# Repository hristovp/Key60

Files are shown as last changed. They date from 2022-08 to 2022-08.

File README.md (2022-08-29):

I made a custom 60%(61 keys) keyboard with custom made PCB using (ATmega32u4) which is completely customizable.
I am adding evething needed for the project. It just take time to check if everythins works. :D

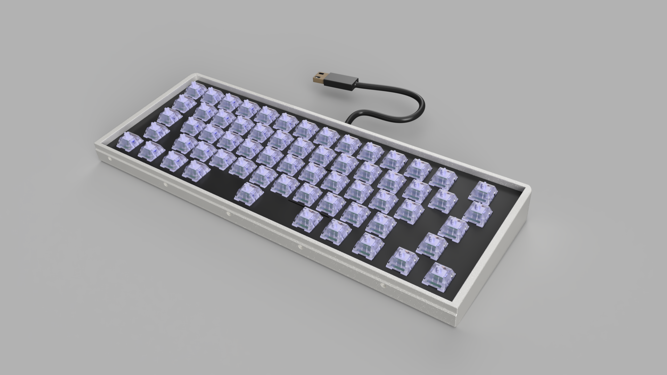
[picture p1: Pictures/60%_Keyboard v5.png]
<kbd></kbd> <kbd></kbd>
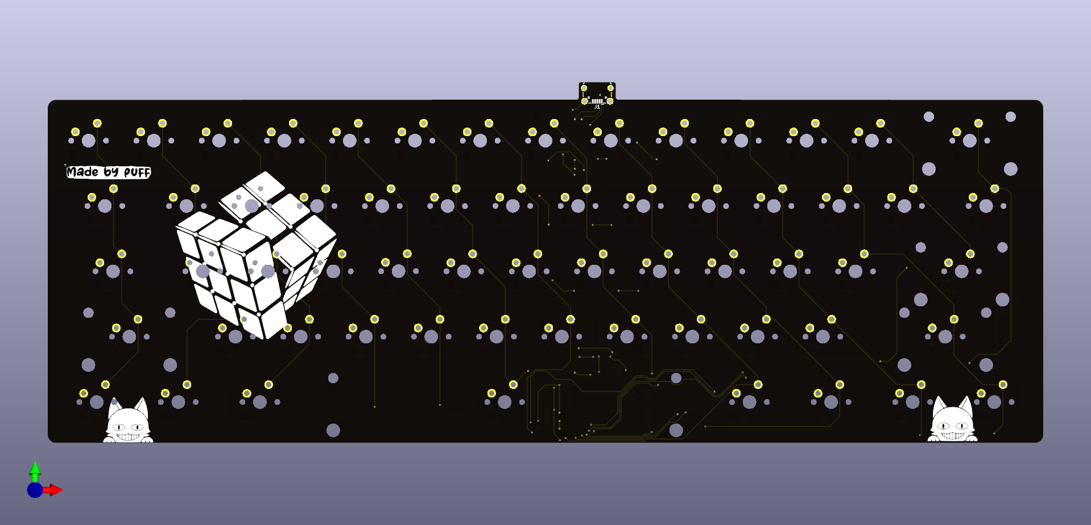
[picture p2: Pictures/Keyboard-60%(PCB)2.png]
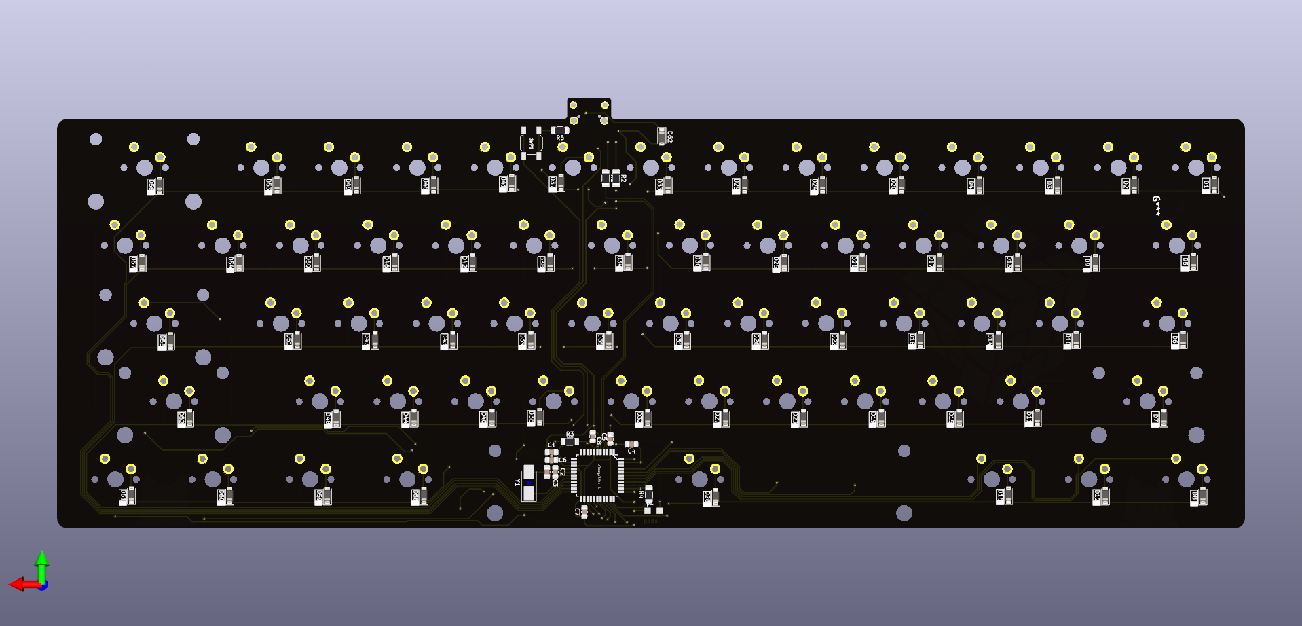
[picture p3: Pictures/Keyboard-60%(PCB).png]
<kbd></kbd> <kbd></kbd>

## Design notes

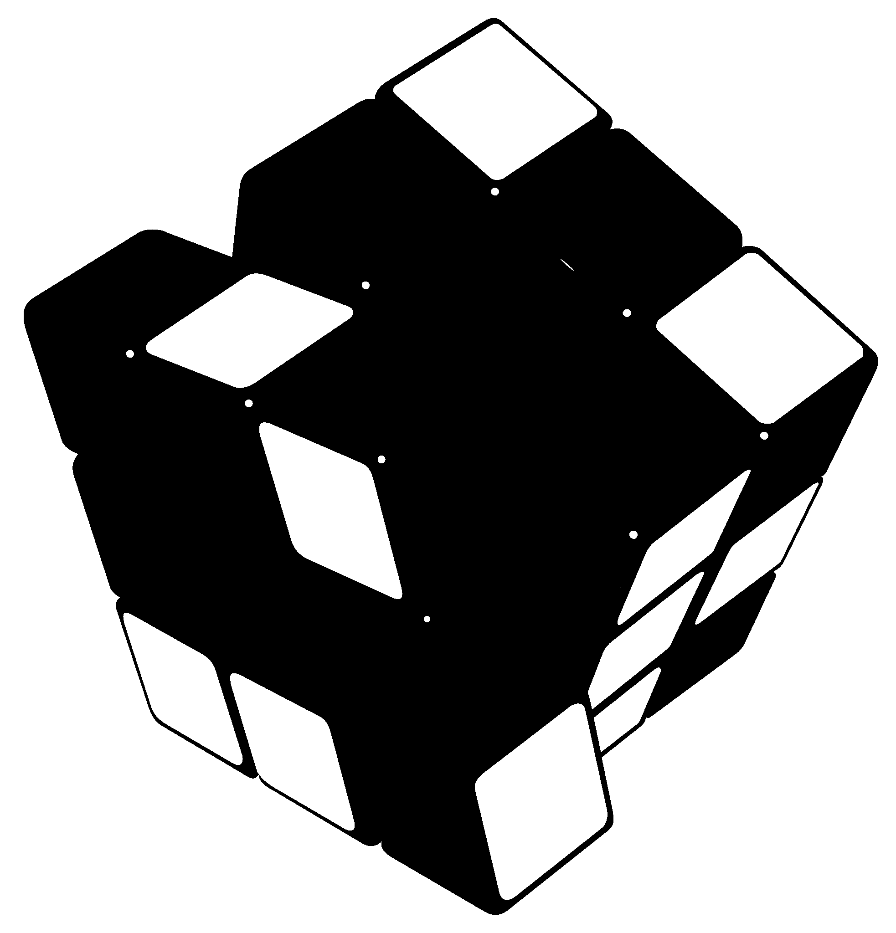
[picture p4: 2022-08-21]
KiKad/Keyboard-60%/img/1966px-Rubik's_cube.bmp

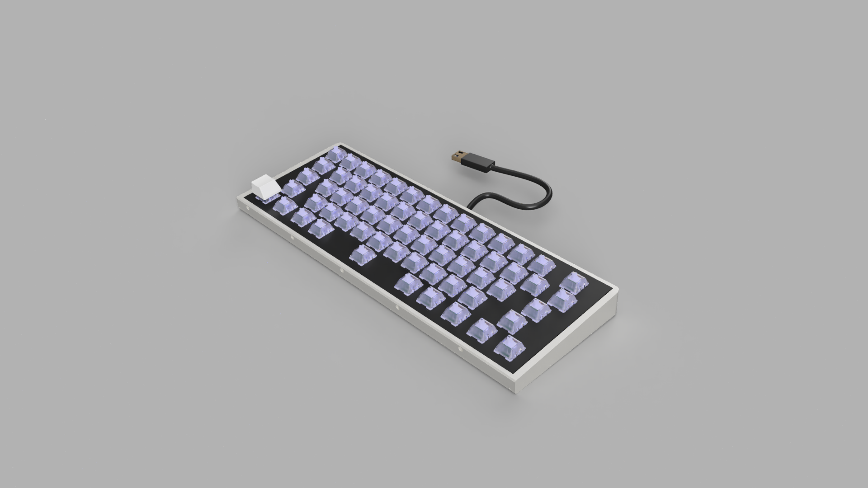
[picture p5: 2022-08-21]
Pictures/60%_Keyboard v2.png

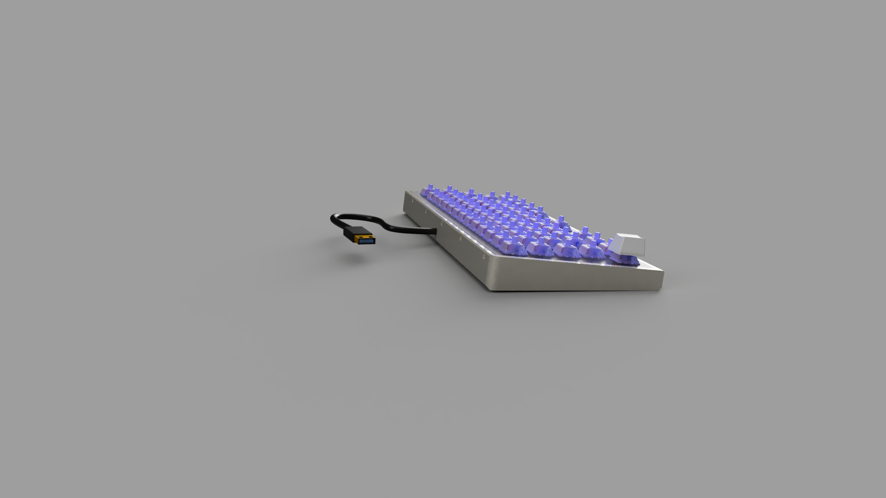
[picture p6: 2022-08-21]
Pictures/60%_Keyboard v3.png

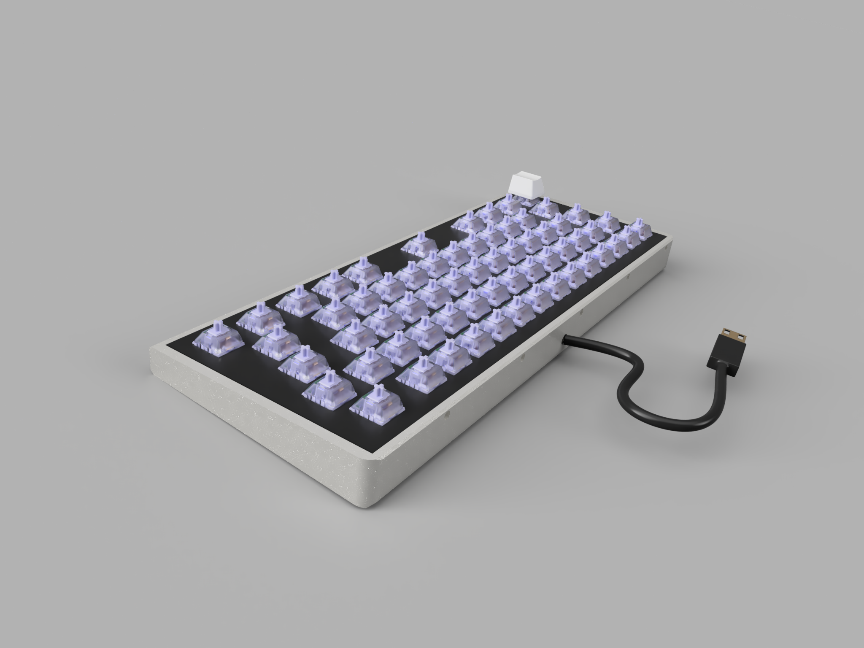
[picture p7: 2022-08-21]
Pictures/60%_Keyboard v4.png

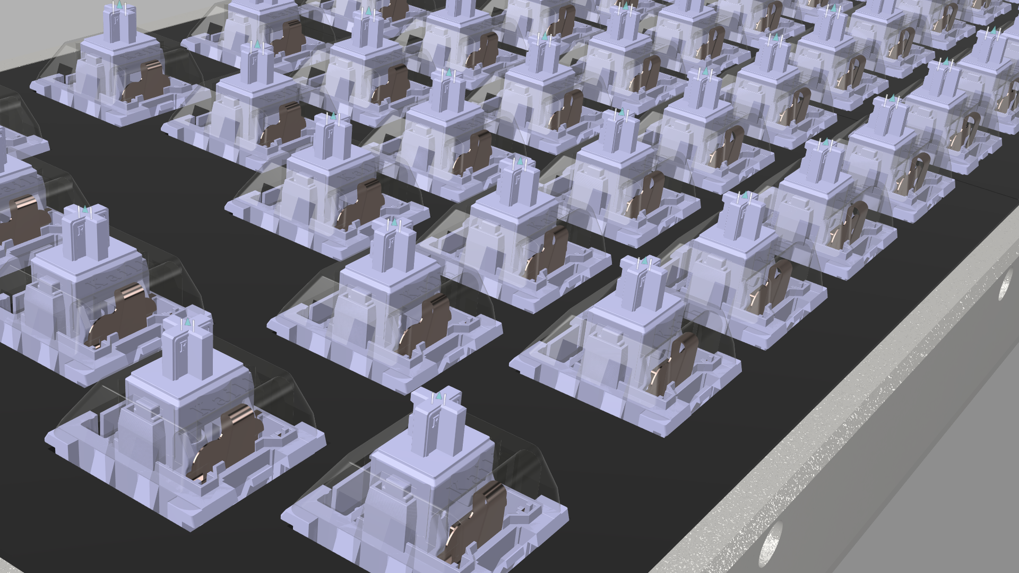
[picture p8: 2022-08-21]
Pictures/60%_Keyboard v1.png

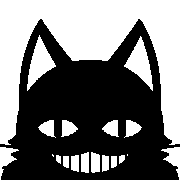
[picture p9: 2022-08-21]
KiKad/Keyboard-60%/img/cat1467410768667.png.ff3f7331aa8d5c62bf9b5040716ce16c.thumb.png.339970b88bf1293ce4fa12bc12f244e9.bmp

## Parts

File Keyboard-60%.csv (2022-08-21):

Source: | D:\PCB\KiKad\Keyboard-60%\Keyboard-60%.kicad_sch
Date: | 21.8.2022 г. 15:45:35
Tool: | Eeschema (6.0.6)
Generator: | D:\Program Files\KiCad\6.0\bin\scripting\plugins/bom_csv_grouped_by_value_with_fp.py
Component Count: | 141
Ref | Qnty | Value | Cmp name | Footprint | Description | Vendor
C1, | 1 | 100nF | C_Small | Capacitor_SMD:C_0805_2012Metric_Pad1.18x1.45mm_HandSolder | Unpolarized capacitor, small symbol
C2, C3, | 2 | 22pF | C_Small | Capacitor_SMD:C_0805_2012Metric_Pad1.18x1.45mm_HandSolder | Unpolarized capacitor, small symbol
C4, | 1 | 1uF | C_Small | Capacitor_SMD:C_0805_2012Metric_Pad1.18x1.45mm_HandSolder | Unpolarized capacitor, small symbol
C5, C6, C7, C8, | 4 | 100n | C_Small | Capacitor_SMD:C_0805_2012Metric_Pad1.18x1.45mm_HandSolder | Unpolarized capacitor, small symbol
D1, D2, D3, D4, D5, D6, D7, D8, D9, D10, D11, D12, D13, D14, D15, D16, D17, D18, D19, D20, D21, D22, D23, D24, D25, D26, D27, D28, D29, D30, D31, D32, D33, D34, D35, D36, D37, D38, D39, D40, D41, D42, D43, D44, D45, D46, D47, D48, D49, D50, D51, D52, D53, D54, D55, D56, D57, D58, D59, D60, D61, D62, | 62 | 1N4148W | D_Small | Diode_SMD:D_SOD-123 | Diode, small symbol
J1, | 1 | USB_B_Micro | USB_B_Micro | Connector_USB:USB_Micro-B_Wuerth_629105150521_CircularHoles | USB Micro Type B connector
p1, | 1 | pads_2mm | pads_2mm | MyElements:pad-2mm | Fuse
R1, R2, | 2 | 22R | R_Small | Resistor_SMD:R_1206_3216Metric_Pad1.30x1.75mm_HandSolder | Resistor, small symbol
R3, | 1 | 10K | R_Small | Resistor_SMD:R_1206_3216Metric_Pad1.30x1.75mm_HandSolder | Resistor, small symbol
R4, | 1 | 1K | R_Small | Resistor_SMD:R_1206_3216Metric_Pad1.30x1.75mm_HandSolder | Resistor, small symbol
R5, | 1 | 330R | R_Small | Resistor_SMD:R_1206_3216Metric_Pad1.30x1.75mm_HandSolder | Resistor, small symbol
SW1, | 1 | ` | MXSwitch | acheron_MX:MX100
SW2, | 1 | 1 | MXSwitch | acheron_MX:MX100
SW3, | 1 | 2 | MXSwitch | acheron_MX:MX100
SW4, | 1 | 3 | MXSwitch | acheron_MX:MX100
SW5, | 1 | Tab_1.5 | MXSwitch | acheron_MX:MX150
SW6, | 1 | CAPS_1.75 | MXSwitch | acheron_MX:MX175
SW7, | 1 | SHIFT_2.25 | MXSwitch | acheron_MX:MX225
SW8, SW61, | 2 | CTRL | MXSwitch | acheron_MX:MX125
SW9, | 1 | Q | MXSwitch | acheron_MX:MX100
SW10, | 1 | A | MXSwitch | acheron_MX:MX100
SW11, | 1 | Z | MXSwitch | acheron_MX:MX100
SW12, SW59, | 2 | WIN | MXSwitch | acheron_MX:MX125
SW13, | 1 | W | MXSwitch | acheron_MX:MX100
SW14, | 1 | S | MXSwitch | acheron_MX:MX100
SW15, | 1 | X | MXSwitch | acheron_MX:MX100
SW16, SW58, | 2 | ALT | MXSwitch | acheron_MX:MX125
SW17, | 1 | E | MXSwitch | acheron_MX:MX100
SW18, | 1 | D | MXSwitch | acheron_MX:MX100
SW19, | 1 | C | MXSwitch | acheron_MX:MX100
SW20, | 1 | 4 | MXSwitch | acheron_MX:MX100
SW21, | 1 | R | MXSwitch | acheron_MX:MX100
SW22, | 1 | F | MXSwitch | acheron_MX:MX100
SW23, | 1 | V | MXSwitch | acheron_MX:MX100
SW24, | 1 | 5 | MXSwitch | acheron_MX:MX100
SW25, | 1 | T | MXSwitch | acheron_MX:MX100
SW26, | 1 | G | MXSwitch | acheron_MX:MX100
SW27, | 1 | B | MXSwitch | acheron_MX:MX100
SW28, | 1 | SPACE_3.75 | MXSwitch | acheron_MX:MX625
SW29, | 1 | 6 | MXSwitch | acheron_MX:MX100
SW30, | 1 | Y | MXSwitch | acheron_MX:MX100
SW31, | 1 | H | MXSwitch | acheron_MX:MX100
SW32, | 1 | N | MXSwitch | acheron_MX:MX100
SW33, | 1 | 7 | MXSwitch | acheron_MX:MX100
SW34, | 1 | U | MXSwitch | acheron_MX:MX100
SW35, | 1 | J | MXSwitch | acheron_MX:MX100
SW36, | 1 | M | MXSwitch | acheron_MX:MX100
SW37, | 1 | 8 | MXSwitch | acheron_MX:MX100
SW38, | 1 | I | MXSwitch | acheron_MX:MX100
SW39, | 1 | K | MXSwitch | acheron_MX:MX100
SW40, | 1 | < | MXSwitch | acheron_MX:MX100
SW41, | 1 | 9 | MXSwitch | acheron_MX:MX100
SW42, | 1 | O | MXSwitch | acheron_MX:MX100
SW43, | 1 | L | MXSwitch | acheron_MX:MX100
SW44, | 1 | > | MXSwitch | acheron_MX:MX100
SW45, | 1 | 0 | MXSwitch | acheron_MX:MX100
SW46, | 1 | P | MXSwitch | acheron_MX:MX100
SW47, | 1 | : | MXSwitch | acheron_MX:MX100
SW48, | 1 | ? | MXSwitch | acheron_MX:MX100
SW49, | 1 | - | MXSwitch | acheron_MX:MX100
SW50, | 1 | { | MXSwitch | acheron_MX:MX100
SW51, | 1 | " | MXSwitch | acheron_MX:MX100
SW52, | 1 | SHIFT_2.75 | MXSwitch | acheron_MX:MX275
SW53, | 1 | = | MXSwitch | acheron_MX:MX100
SW54, | 1 | } | MXSwitch | acheron_MX:MX100
SW55, | 1 | ENTER_2.25 | MXSwitch | acheron_MX:MX225
SW56, | 1 | Backspace_2 | MXSwitch | acheron_MX:MX200
SW57, | 1 | \_1.5 | MXSwitch | acheron_MX:MX150
SW60, | 1 | MENU | MXSwitch | acheron_MX:MX125
SWP1, | 1 | SW_Push | SW_Push | acheron_Hardware:K2-1187SQ-A4SW-06 | Push button switch, generic, two pins
U1, | 1 | ATmega32U4-A | ATmega32U4-A | ATmega32U4:ATmega32U4 | 16MHz, 32kB Flash, 2.5kB SRAM, 1kB EEPROM, USB 2.0, TQFP-44
Y1, | 1 | 16MHz | Crystal_Small | Crystal:Crystal_SMD_5032-2Pin_5.0x3.2mm_HandSoldering | Two pin crystal, small symbol

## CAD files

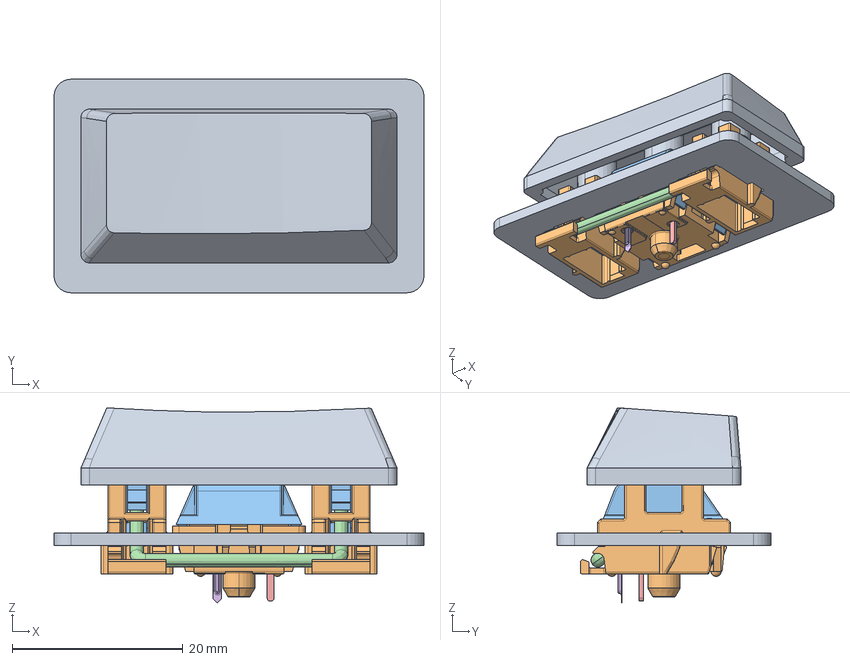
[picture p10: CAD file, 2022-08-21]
KiKad/Keyboard-60%/cherry-plate-mount-stabilizer-1.snapshot.5/as_stabil_asm.stp
43.3 x 25.0 x 22.8 mm
PLATE_STABIL3
MX_DOWN
MX_UP
UP_MX
MX_PIN
MX_SPRING
MX_CLICK
ENTER
STABIL_DOWN_MX x 2
STABIL_MX x 2
MX_METAL

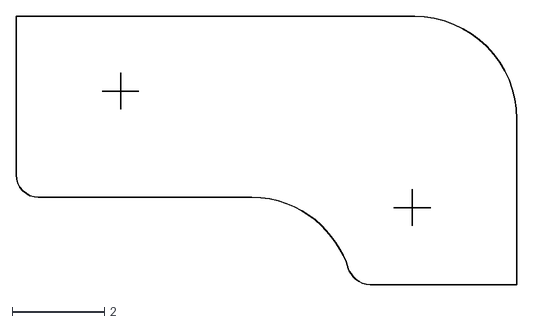
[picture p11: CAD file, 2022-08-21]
KiKad/Keyboard-60%/AlexandriaLibrary-master/graphics/kailhMxSocketOutline.dxf
10.8 x 5.81

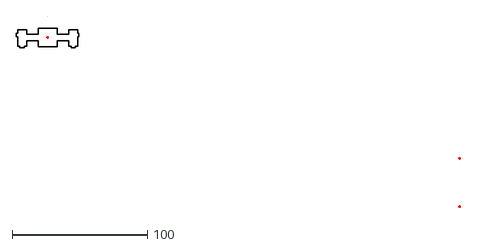
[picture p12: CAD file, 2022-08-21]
KiKad/Keyboard-60%/AlexandriaLibrary-master/graphics/plate_cutouts/3U.dxf
329.0 x 141.8

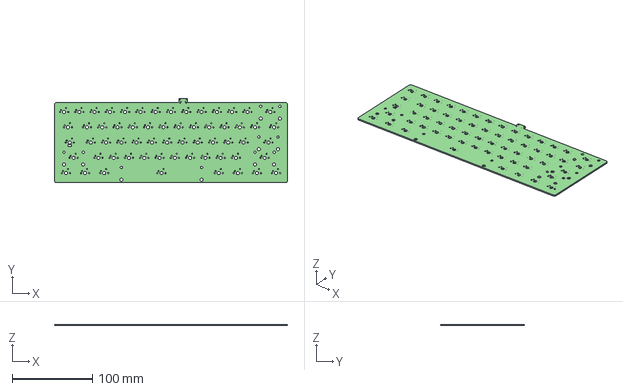
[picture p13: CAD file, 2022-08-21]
KiKad/Keyboard-60%/Keyboard-60%.step
290.5 x 105.2 x 1.60 mm

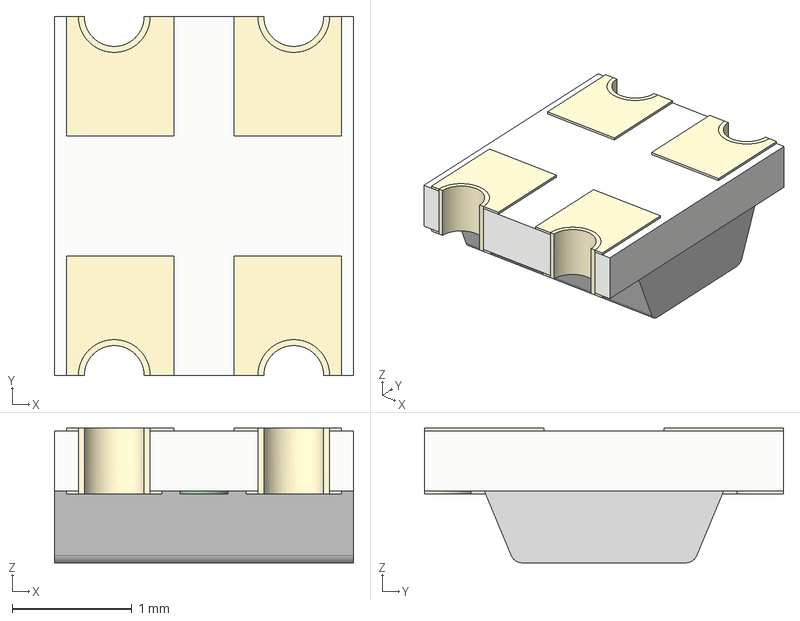
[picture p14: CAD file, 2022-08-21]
KiKad/Keyboard-60%/AlexandriaLibrary-master/3d_models/E6C1209RGB.iges
2.50 x 3.00 x 1.12 mm

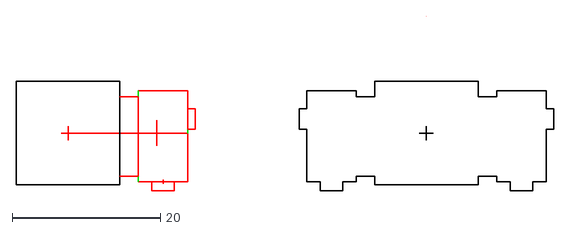
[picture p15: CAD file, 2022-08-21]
KiKad/Keyboard-60%/AlexandriaLibrary-master/graphics/plate_cutouts/2U.dxf
72.6 x 23.5

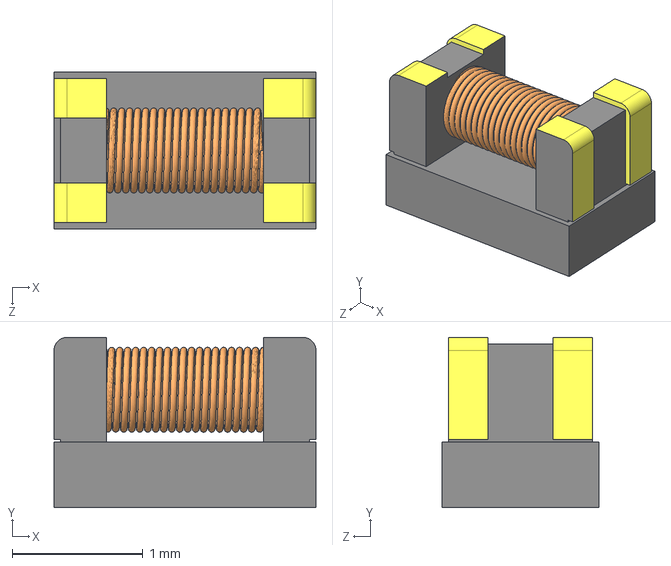
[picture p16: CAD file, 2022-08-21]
KiKad/Keyboard-60%/AlexandriaLibrary-master/3d_models/ACM2012-2P.STEP
2.00 x 1.30 x 1.20 mm

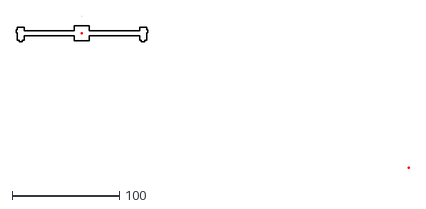
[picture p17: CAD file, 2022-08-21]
KiKad/Keyboard-60%/AlexandriaLibrary-master/graphics/plate_cutouts/7U.dxf
367.1 x 141.8

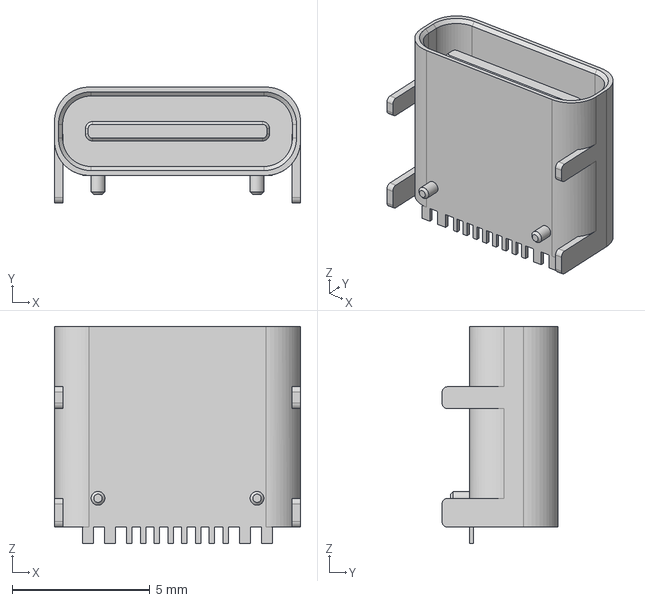
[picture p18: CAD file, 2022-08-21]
KiKad/Keyboard-60%/AlexandriaLibrary-master/3d_models/TYPE-C-31-M-12.step
8.94 x 4.21 x 7.90 mm

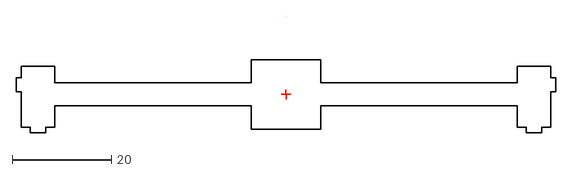
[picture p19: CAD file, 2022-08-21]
KiKad/Keyboard-60%/AlexandriaLibrary-master/graphics/plate_cutouts/6.25U.dxf
108.6 x 23.5

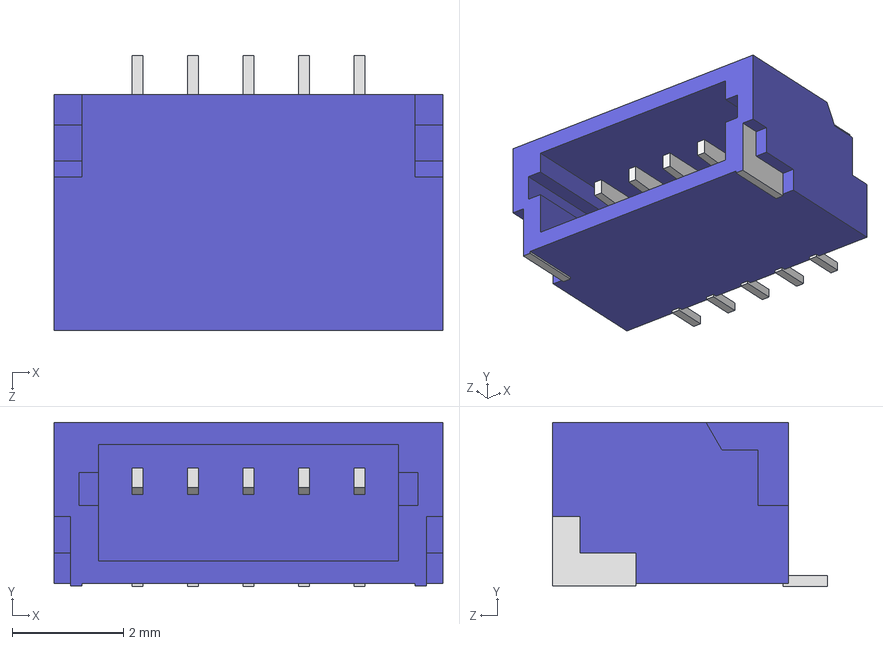
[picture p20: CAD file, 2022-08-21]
KiKad/Keyboard-60%/AlexandriaLibrary-master/3d_models/SM05B-SRSS-TB.STEP
7.00 x 2.96 x 4.95 mm

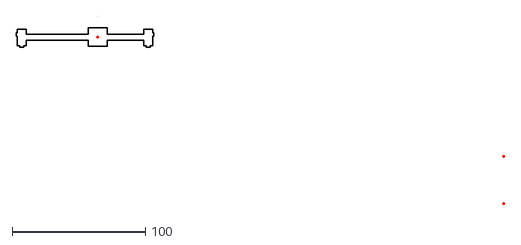
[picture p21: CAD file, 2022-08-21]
KiKad/Keyboard-60%/AlexandriaLibrary-master/graphics/plate_cutouts/6U.dxf
367.0 x 141.8

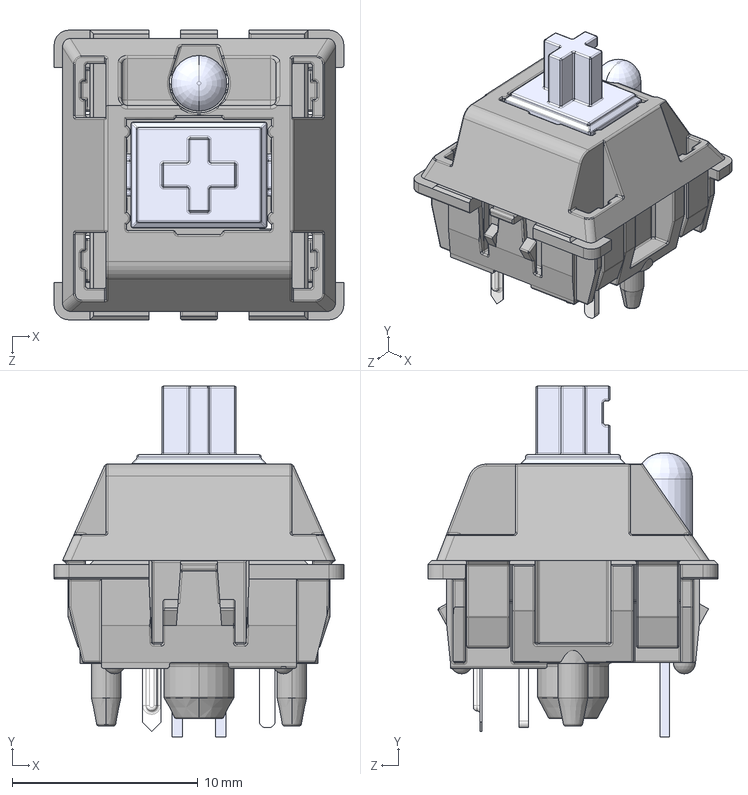
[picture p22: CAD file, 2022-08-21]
KiKad/Keyboard-60%/AlexandriaLibrary-master/3d_models/mx_switch.step
15.6 x 18.9 x 15.6 mm
MX 轴 按键′_ü___¨1
MX 轴 轴体áì_¨￠¨__
MX粣 拸簽LEDLEDLED
MX轴 轴体 底部 μ×2__默认_á2____è_
针脚___默认__è_

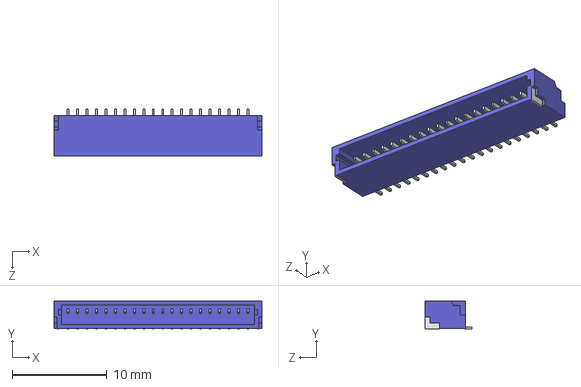
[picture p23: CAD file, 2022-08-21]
KiKad/Keyboard-60%/AlexandriaLibrary-master/3d_models/SM20B-SRSS-TB.STEP
22.0 x 2.96 x 4.95 mm

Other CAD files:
KiKad/Keyboard-60%/AlexandriaLibrary-master/3d_models/OSC5032.STEP
KiKad/Keyboard-60%/AlexandriaLibrary-master/3d_models/SM13B-SRSS-TB.STEP
KiKad/Keyboard-60%/AlexandriaLibrary-master/3d_models/WS2812.stp
KiKad/Keyboard-60%/AlexandriaLibrary-master/3d_models/3313J-1-202E.stp
KiKad/Keyboard-60%/AlexandriaLibrary-master/3d_models/4PinHeader.step
KiKad/Keyboard-60%/AlexandriaLibrary-master/3d_models/5032_XTAL.step
KiKad/Keyboard-60%/AlexandriaLibrary-master/3d_models/6028SMDRGB.iges
KiKad/Keyboard-60%/AlexandriaLibrary-master/3d_models/9774010243.stp
KiKad/Keyboard-60%/AlexandriaLibrary-master/3d_models/9774030243R.step
KiKad/Keyboard-60%/AlexandriaLibrary-master/3d_models/ALPS_EC11E.stp
KiKad/Keyboard-60%/AlexandriaLibrary-master/3d_models/BM04B-ASRS-TF.STEP
KiKad/Keyboard-60%/AlexandriaLibrary-master/3d_models/BM04B-SRSS.step
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

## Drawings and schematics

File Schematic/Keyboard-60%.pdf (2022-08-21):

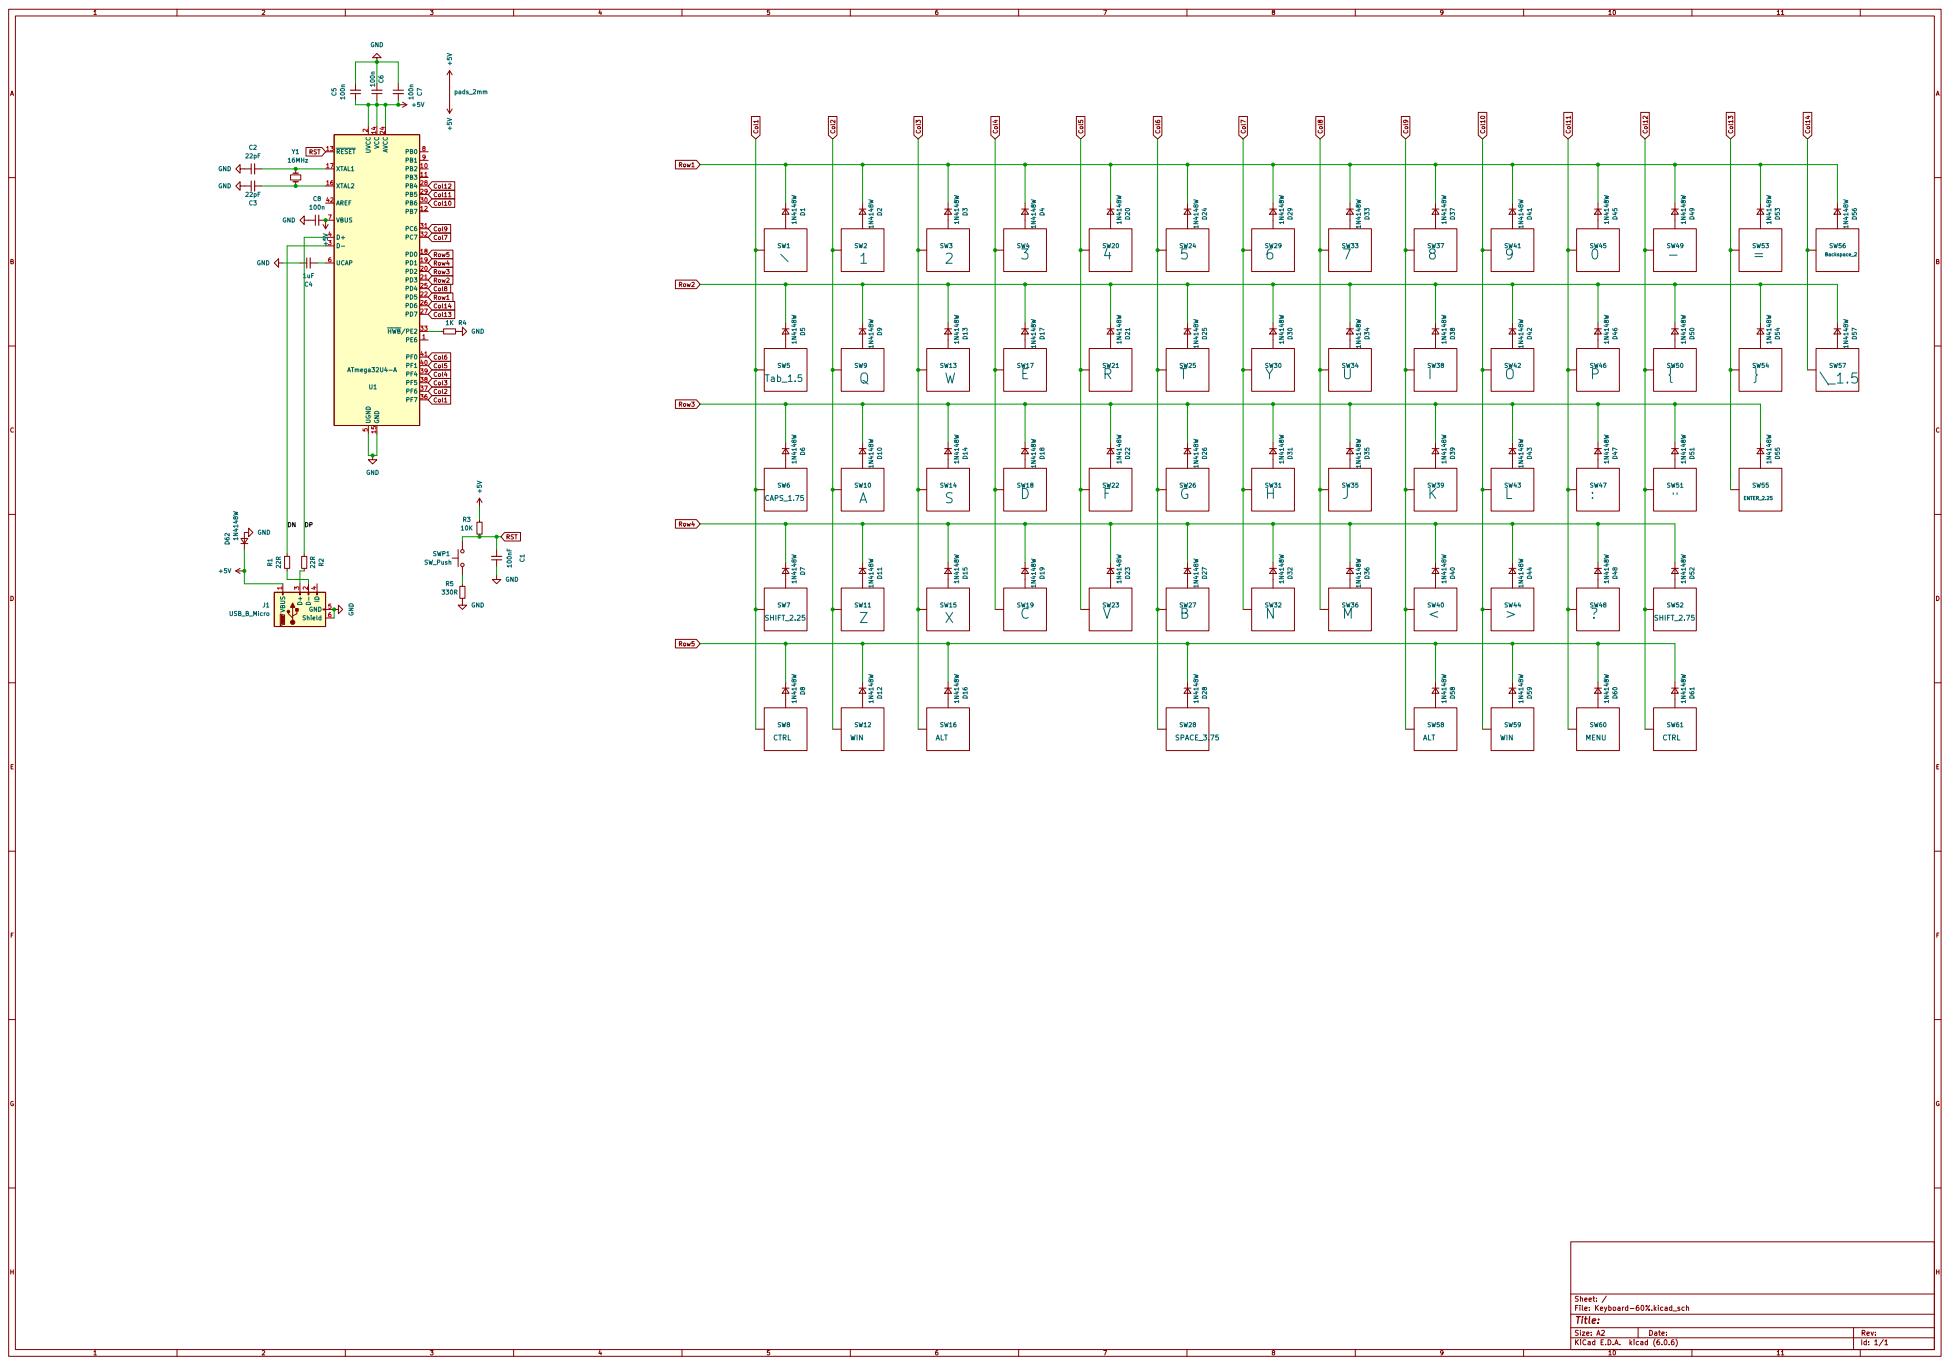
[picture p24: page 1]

2 PD2 20 PD3 21 PD5 22 AVCC 24 PD4 25 PD6 26 PD7 27 PB4 28 PB5 29 D- 3 PB6 30 PC6 31 PC7 32 ~{HWB}/PE233 PF7 36 PF6 37 PF5 38 PF4 39 D+ 4 PF1 40 PF0 41 AREF 42 UGND

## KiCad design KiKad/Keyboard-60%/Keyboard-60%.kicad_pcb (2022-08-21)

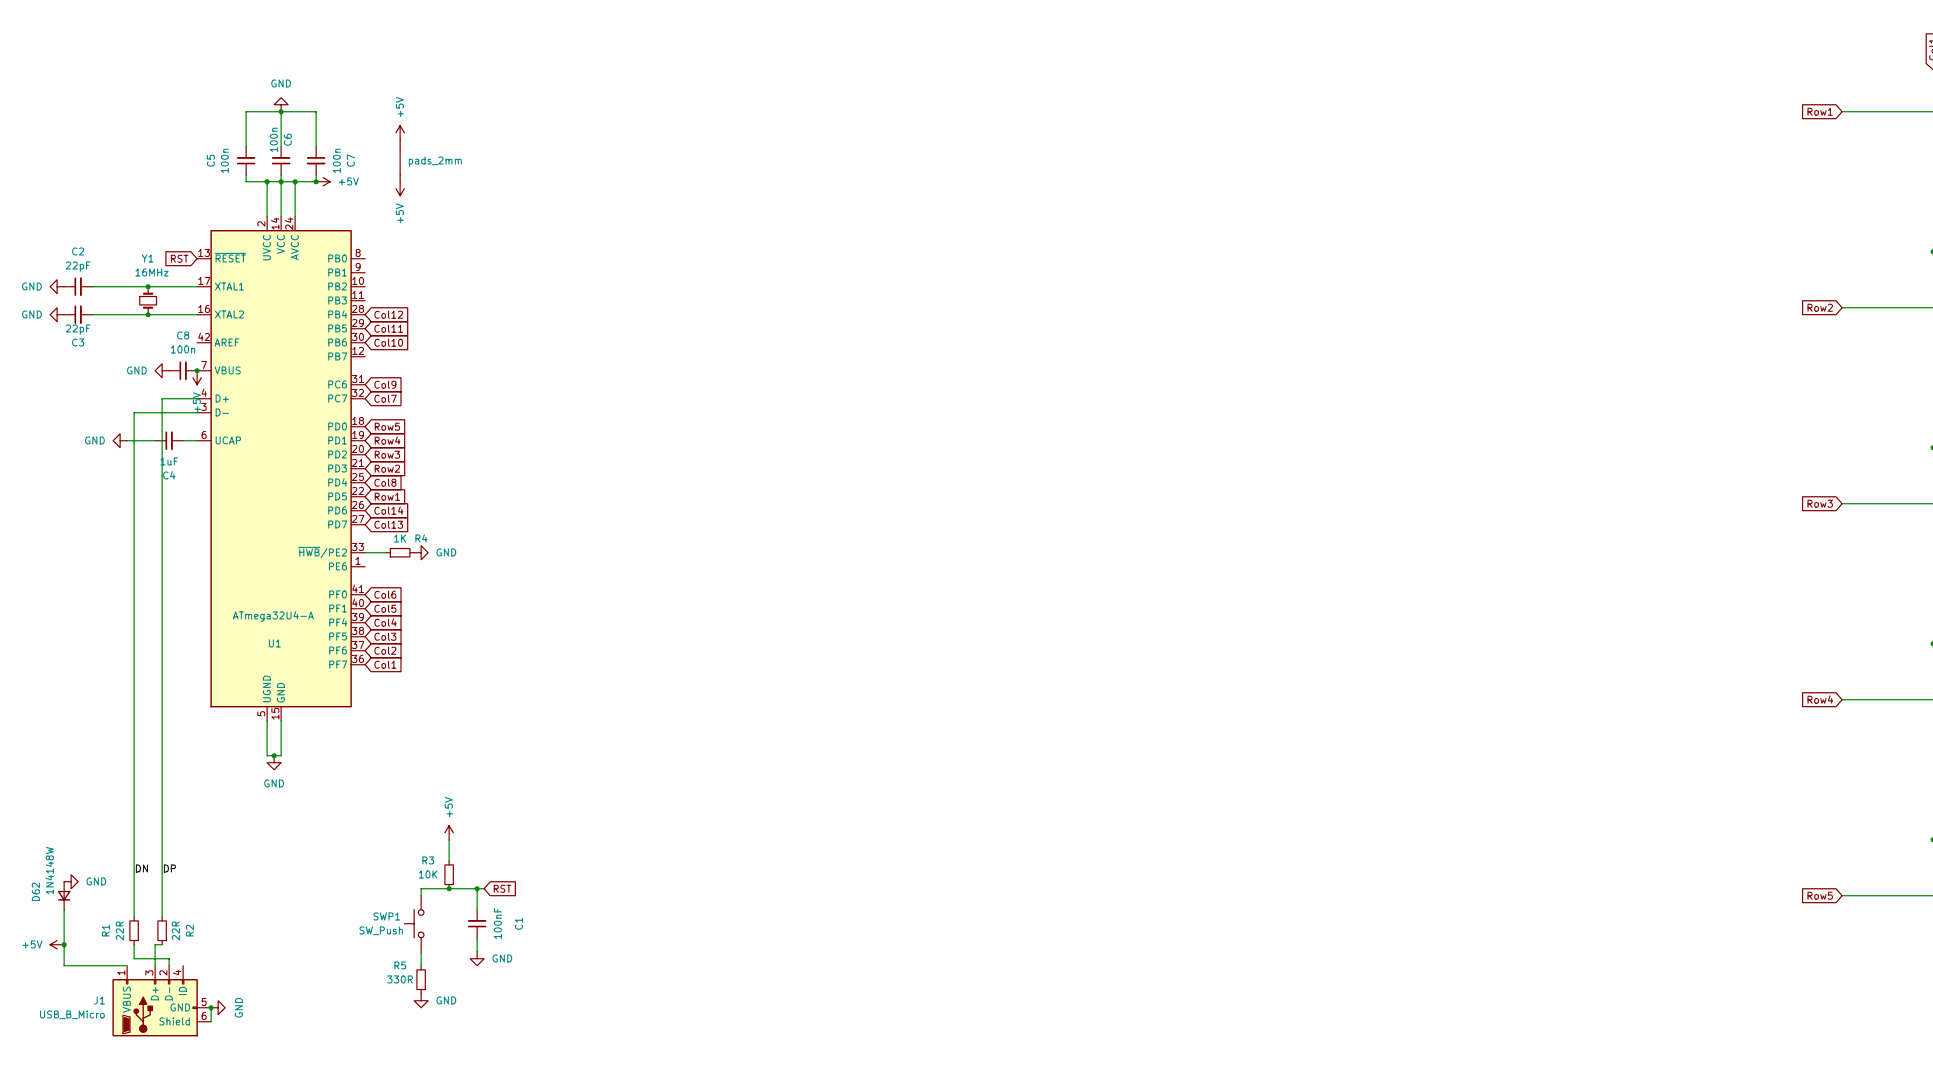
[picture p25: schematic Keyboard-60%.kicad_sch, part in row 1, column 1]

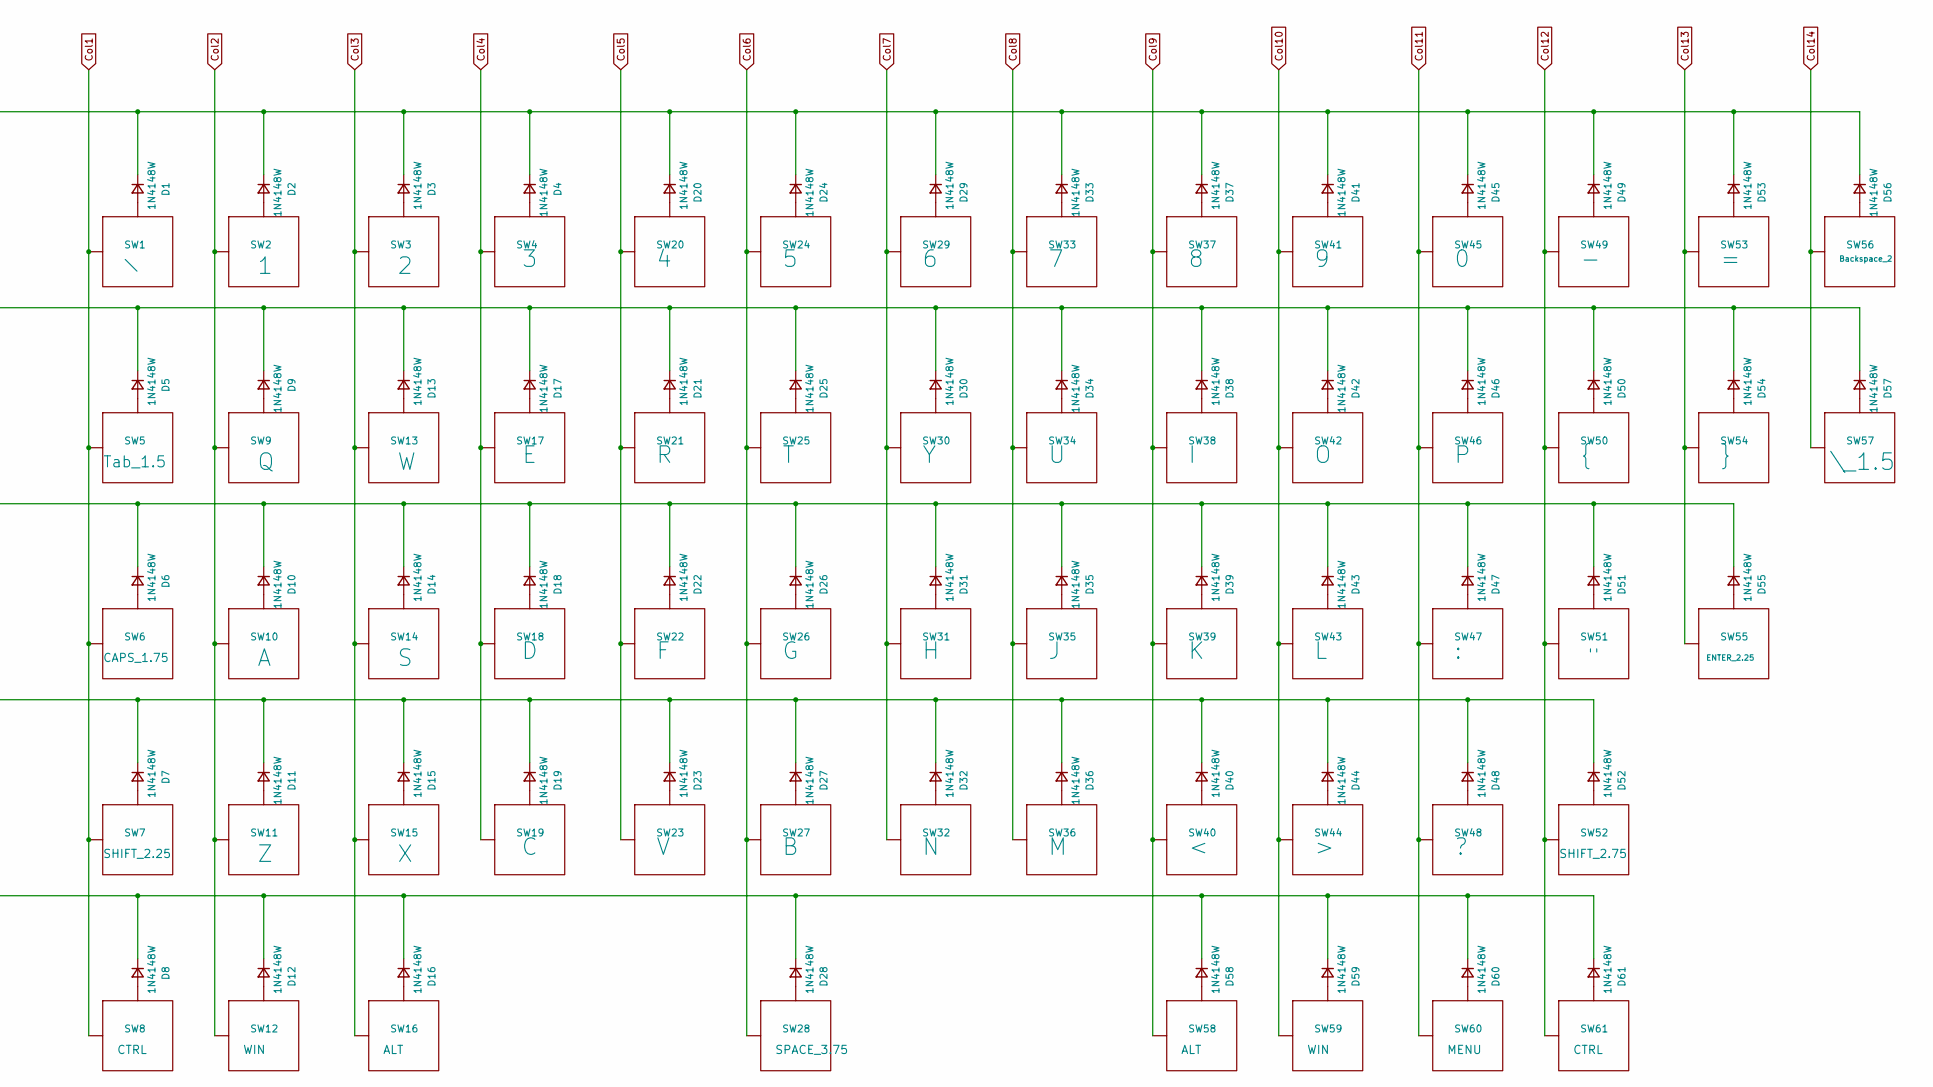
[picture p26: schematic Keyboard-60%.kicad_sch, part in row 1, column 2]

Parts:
C1: 100nF; C_0805_2012Metric_Pad1.18x1.45mm_HandSolder
C2, C3: 22pF; C_0805_2012Metric_Pad1.18x1.45mm_HandSolder
C4: 1uF; C_0805_2012Metric_Pad1.18x1.45mm_HandSolder
C5, C6, C7, C8: 100n; C_0805_2012Metric_Pad1.18x1.45mm_HandSolder
D1, D2, D3, D4, D5, D6, D7, D8, D9, D10, D11, D12, D13, D14, D15, D16, D17, D18, D19, D20, D21, D22, D23, D24, D25, D26, D27, D28, D29, D30, D31, D32, D33, D34, D35, D36, D37, D38, D39, D40, D41, D42, D43, D44, D45, D46, D47, D48, D49, D50, D51, D52, D53, D54, D55, D56, D57, D58, D59, D60, D61, D62: 1N4148W; D_SOD-123
J1: USB_B_Micro; USB_Micro-B_Wuerth_629105150521_CircularHoles
R1, R2: 22R; R_1206_3216Metric_Pad1.30x1.75mm_HandSolder
R3: 10K; R_1206_3216Metric_Pad1.30x1.75mm_HandSolder
R4: 1K; R_1206_3216Metric_Pad1.30x1.75mm_HandSolder
R5: 330R; R_1206_3216Metric_Pad1.30x1.75mm_HandSolder
SW1: `; MX100
SW2: 1; MX100
SW3: 2; MX100
SW4: 3; MX100
SW5: Tab_1.5; MX150
SW6: CAPS_1.75; MX175
SW7: SHIFT_2.25; MX225
SW8, SW61: CTRL; MX125
SW9: Q; MX100
SW10: A; MX100
SW11: Z; MX100
SW12, SW59: WIN; MX125
SW13: W; MX100
SW14: S; MX100
SW15: X; MX100
SW16, SW58: ALT; MX125
SW17: E; MX100
SW18: D; MX100
SW19: C; MX100
SW20: 4; MX100
SW21: R; MX100
SW22: F; MX100
SW23: V; MX100
SW24: 5; MX100
SW25: T; MX100
SW26: G; MX100
SW27: B; MX100
SW28: SPACE_3.75; MX625
SW29: 6; MX100
SW30: Y; MX100
SW31: H; MX100
SW32: N; MX100
SW33: 7; MX100
SW34: U; MX100
SW35: J; MX100
SW36: M; MX100
SW37: 8; MX100
SW38: I; MX100
SW39: K; MX100
SW40: <; MX100
SW41: 9; MX100
SW42: O; MX100
SW43: L; MX100
SW44: >; MX100
SW45: 0; MX100
SW46: P; MX100
SW47: :; MX100
SW48: ?; MX100
SW49: -; MX100
SW50: {; MX100
SW51: "; MX100
SW52: SHIFT_2.75; MX275
SW53: =; MX100
SW54: }; MX100
SW55: ENTER_2.25; MX225
SW56: Backspace_2; MX200
SW57: \_1.5; MX150
SW60: MENU; MX125
SWP1: SW_Push; K2-1187SQ-A4SW-06
U1: ATmega32U4-A; ATmega32U4
Y1: 16MHz; Crystal_SMD_5032-2Pin_5.0x3.2mm_HandSoldering
p1: pads_2mm; pad-2mm

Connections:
+5V: C5.1, C6.1, C7.2, C8.2, D62.1 (K), J1.1 (VBUS), R3.2, U1.2 (UVCC), U1.7 (VBUS), U1.14 (VCC), U1.24 (AVCC), U1.34 (VCC), U1.44 (AVCC), p1.1, p1.2
/DN: R1.2, U1.3 (D-)
/DP: R2.2, U1.4 (D+)
Col1: SW1.1 (Col), SW5.1 (Col), SW6.1 (Col), SW7.1 (Col), SW8.1 (Col), U1.36 (PF7)
Col2: SW2.1 (Col), SW9.1 (Col), SW10.1 (Col), SW11.1 (Col), SW12.1 (Col), U1.37 (PF6)
Col3: SW3.1 (Col), SW13.1 (Col), SW14.1 (Col), SW15.1 (Col), SW16.1 (Col), U1.38 (PF5)
Col4: SW4.1 (Col), SW17.1 (Col), SW18.1 (Col), SW19.1 (Col), U1.39 (PF4)
Col5: SW20.1 (Col), SW21.1 (Col), SW22.1 (Col), SW23.1 (Col), U1.40 (PF1)
Col6: SW24.1 (Col), SW25.1 (Col), SW26.1 (Col), SW27.1 (Col), SW28.1 (Col), U1.41 (PF0)
Col7: SW29.1 (Col), SW30.1 (Col), SW31.1 (Col), SW32.1 (Col), U1.32 (PC7)
Col8: SW33.1 (Col), SW34.1 (Col), SW35.1 (Col), SW36.1 (Col), U1.25 (PD4)
Col9: SW37.1 (Col), SW38.1 (Col), SW39.1 (Col), SW40.1 (Col), SW58.1 (Col), U1.31 (PC6)
Col10: SW41.1 (Col), SW42.1 (Col), SW43.1 (Col), SW44.1 (Col), SW59.1 (Col), U1.30 (PB6)
Col11: SW45.1 (Col), SW46.1 (Col), SW47.1 (Col), SW48.1 (Col), SW60.1 (Col), U1.29 (PB5)
Col12: SW49.1 (Col), SW50.1 (Col), SW51.1 (Col), SW52.1 (Col), SW61.1 (Col), U1.28 (PB4)
Col13: SW53.1 (Col), SW54.1 (Col), SW55.1 (Col), U1.27 (PD7)
Col14: SW56.1 (Col), SW57.1 (Col), U1.26 (PD6)
GND: C1.1, C2.1, C3.1, C4.1, C5.2, C6.2, C7.1, C8.1, D62.2 (A), J1.5 (GND), J1.6 (Shield), R4.2, R5.1, U1.5 (UGND), U1.15 (GND), U1.23 (GND), U1.35 (GND), U1.43 (GND)
unnamed: C2.2, U1.17 (XTAL1), Y1.1
unnamed: C3.2, U1.16 (XTAL2), Y1.2
unnamed: C4.2, U1.6 (UCAP)
unnamed: D1.2 (A), SW1.2 (Row)
unnamed: D2.2 (A), SW2.2 (Row)
unnamed: D3.2 (A), SW3.2 (Row)
unnamed: D4.2 (A), SW4.2 (Row)
unnamed: D5.2 (A), SW5.2 (Row)
unnamed: D6.2 (A), SW6.2 (Row)
unnamed: D7.2 (A), SW7.2 (Row)
unnamed: D8.2 (A), SW8.2 (Row)
unnamed: D9.2 (A), SW9.2 (Row)
unnamed: D10.2 (A), SW10.2 (Row)
unnamed: D11.2 (A), SW11.2 (Row)
unnamed: D12.2 (A), SW12.2 (Row)
unnamed: D13.2 (A), SW13.2 (Row)
unnamed: D14.2 (A), SW14.2 (Row)
unnamed: D15.2 (A), SW15.2 (Row)
unnamed: D16.2 (A), SW16.2 (Row)
unnamed: D17.2 (A), SW17.2 (Row)
unnamed: D18.2 (A), SW18.2 (Row)
unnamed: D19.2 (A), SW19.2 (Row)
unnamed: D20.2 (A), SW20.2 (Row)
unnamed: D21.2 (A), SW21.2 (Row)
unnamed: D22.2 (A), SW22.2 (Row)
unnamed: D23.2 (A), SW23.2 (Row)
unnamed: D24.2 (A), SW24.2 (Row)
unnamed: D25.2 (A), SW25.2 (Row)
unnamed: D26.2 (A), SW26.2 (Row)
unnamed: D27.2 (A), SW27.2 (Row)
unnamed: D28.2 (A), SW28.2 (Row)
unnamed: D29.2 (A), SW29.2 (Row)
unnamed: D30.2 (A), SW30.2 (Row)
unnamed: D31.2 (A), SW31.2 (Row)
unnamed: D32.2 (A), SW32.2 (Row)
unnamed: D33.2 (A), SW33.2 (Row)
unnamed: D34.2 (A), SW34.2 (Row)
unnamed: D35.2 (A), SW35.2 (Row)
unnamed: D36.2 (A), SW36.2 (Row)
unnamed: D37.2 (A), SW37.2 (Row)
unnamed: D38.2 (A), SW38.2 (Row)
unnamed: D39.2 (A), SW39.2 (Row)
unnamed: D40.2 (A), SW40.2 (Row)
unnamed: D41.2 (A), SW41.2 (Row)
unnamed: D42.2 (A), SW42.2 (Row)
unnamed: D43.2 (A), SW43.2 (Row)
unnamed: D44.2 (A), SW44.2 (Row)
unnamed: D45.2 (A), SW45.2 (Row)
unnamed: D46.2 (A), SW46.2 (Row)
unnamed: D47.2 (A), SW47.2 (Row)
unnamed: D48.2 (A), SW48.2 (Row)
unnamed: D49.2 (A), SW49.2 (Row)
unnamed: D50.2 (A), SW50.2 (Row)
unnamed: D51.2 (A), SW51.2 (Row)
unnamed: D52.2 (A), SW52.2 (Row)
unnamed: D53.2 (A), SW53.2 (Row)
unnamed: D54.2 (A), SW54.2 (Row)
unnamed: D55.2 (A), SW55.2 (Row)
unnamed: D56.2 (A), SW56.2 (Row)
unnamed: D57.2 (A), SW57.2 (Row)
unnamed: D58.2 (A), SW58.2 (Row)
unnamed: D59.2 (A), SW59.2 (Row)
unnamed: D60.2 (A), SW60.2 (Row)
unnamed: D61.2 (A), SW61.2 (Row)
unnamed: J1.2 (D-), R1.1
unnamed: J1.3 (D+), R2.1
unnamed: R4.1, U1.33 (~HWB/PE2)
unnamed: R5.2, SWP1.1
RST: C1.2, R3.1, SWP1.2, U1.13 (~RESET)
Row1: D1.1 (K), D2.1 (K), D3.1 (K), D4.1 (K), D20.1 (K), D24.1 (K), D29.1 (K), D33.1 (K), D37.1 (K), D41.1 (K), D45.1 (K), D49.1 (K), D53.1 (K), D56.1 (K), U1.22 (PD5)
Row2: D5.1 (K), D9.1 (K), D13.1 (K), D17.1 (K), D21.1 (K), D25.1 (K), D30.1 (K), D34.1 (K), D38.1 (K), D42.1 (K), D46.1 (K), D50.1 (K), D54.1 (K), D57.1 (K), U1.21 (PD3)
Row3: D6.1 (K), D10.1 (K), D14.1 (K), D18.1 (K), D22.1 (K), D26.1 (K), D31.1 (K), D35.1 (K), D39.1 (K), D43.1 (K), D47.1 (K), D51.1 (K), D55.1 (K), U1.20 (PD2)
Row4: D7.1 (K), D11.1 (K), D15.1 (K), D19.1 (K), D23.1 (K), D27.1 (K), D32.1 (K), D36.1 (K), D40.1 (K), D44.1 (K), D48.1 (K), D52.1 (K), U1.19 (PD1)
Row5: D8.1 (K), D12.1 (K), D16.1 (K), D28.1 (K), D58.1 (K), D59.1 (K), D60.1 (K), D61.1 (K), U1.18 (PD0)

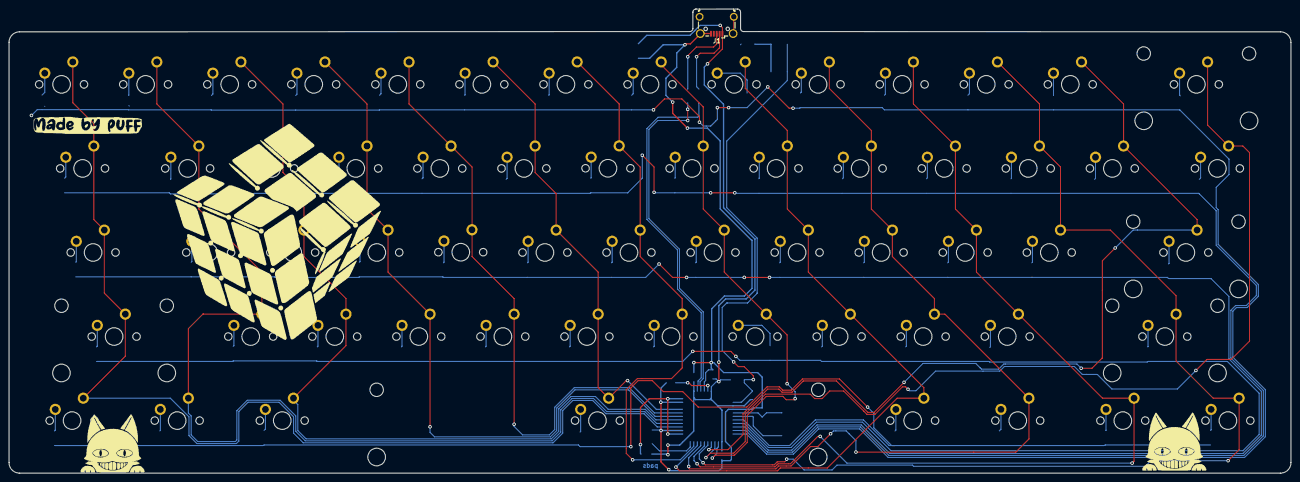
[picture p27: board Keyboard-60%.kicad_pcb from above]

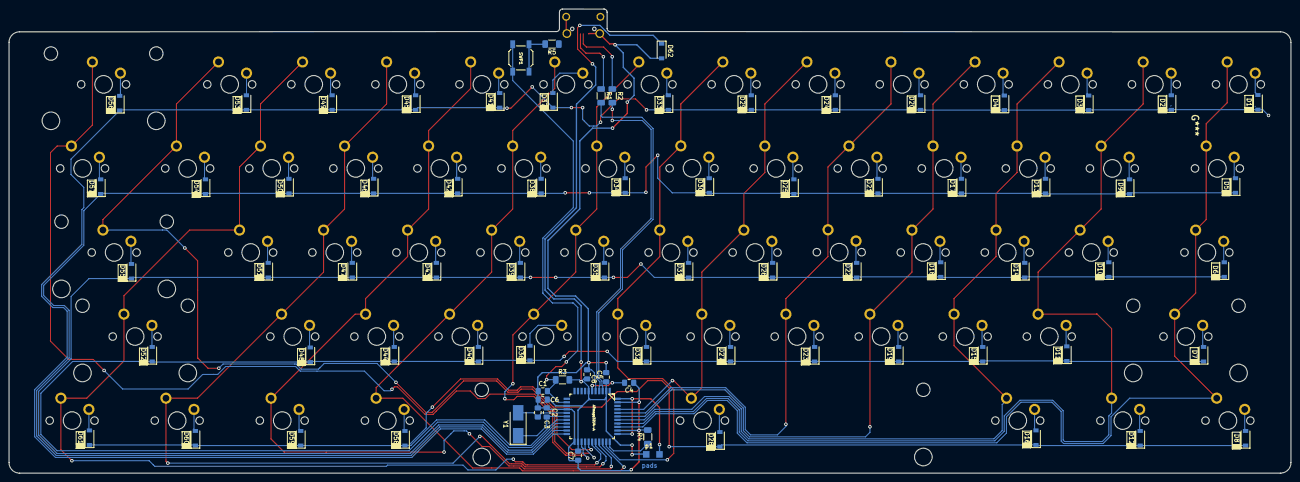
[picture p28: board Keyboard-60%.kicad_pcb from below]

Board: 2 copper layers, 290.5 x 105.2 mm, 141 parts (140 on the bottom side), 92 nets.

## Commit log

2022-08-21 Files and schematics
    [2U.dxf, 2U_switch_plate_cutout.dxf, 3313J-1-202E.stp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]
2022-08-21 PCB picture
